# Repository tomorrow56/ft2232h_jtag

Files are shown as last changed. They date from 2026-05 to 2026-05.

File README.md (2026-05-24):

## FT2232HL JTAG Adapter

### Function

Can be used as Xilinx JTAG downloader & USB-to-UART bridge simultaneously following [this](https://gist.github.com/rikka0w0/24b58b54473227502fa0334bbe75c3c1).

Partly pin-to-pin compatible with the CJMCU FT232HL(the purple PCB one) and has a standard 2x7 JTAG connector.

Main chips: FT2232HL(QFP64), ASM1117(3.3V, SOT89), 93LC56(SOP8).

Type-C(tested later so not shown on pic) connection.

Made with Kicad 10.0.

---
以下の手順に従い、EEPROMにデータを書き込むことで、Xilinx JTAG ダウンローダーと USB-UART ブリッジとして同時に使用できます。

```PowerShell
cd <Vivado install dir>\bin\
.\program_ftdi.bat -write -ftdi FT2232H -serial FT000001 -vendor "Your Name" -board "FT2232H-JTAG" -desc "FT2232H JTAG Adapter"
```

* 標準的な2.54mmピッチの 2x7 JTAGコネクタと 1x4 UARTコネクタを搭載しています
* 主要チップ: FT2232HL(QFP64)、ASM1117(3.3V, SOT89)、93LC56(SOP8)
* Type-C コネクタ搭載

#### 設計環境
KiCad 10.0 で設計

#### Gallery

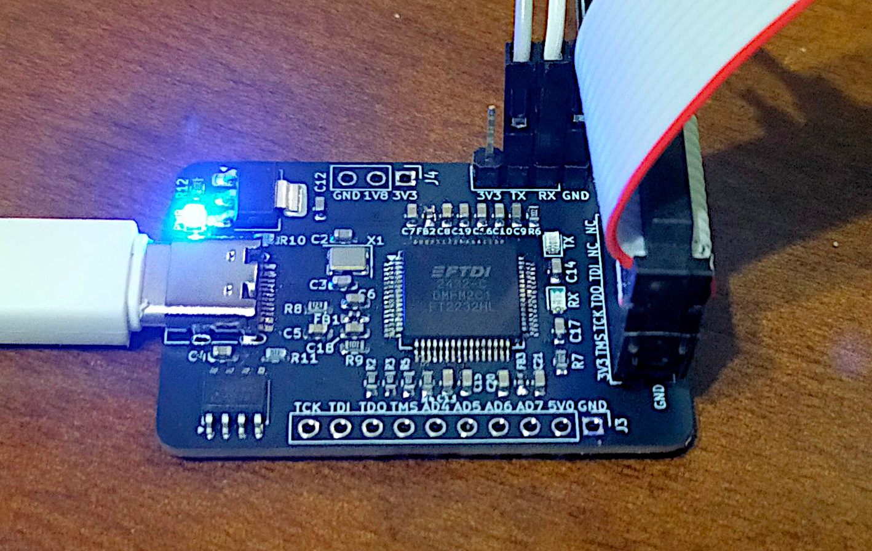
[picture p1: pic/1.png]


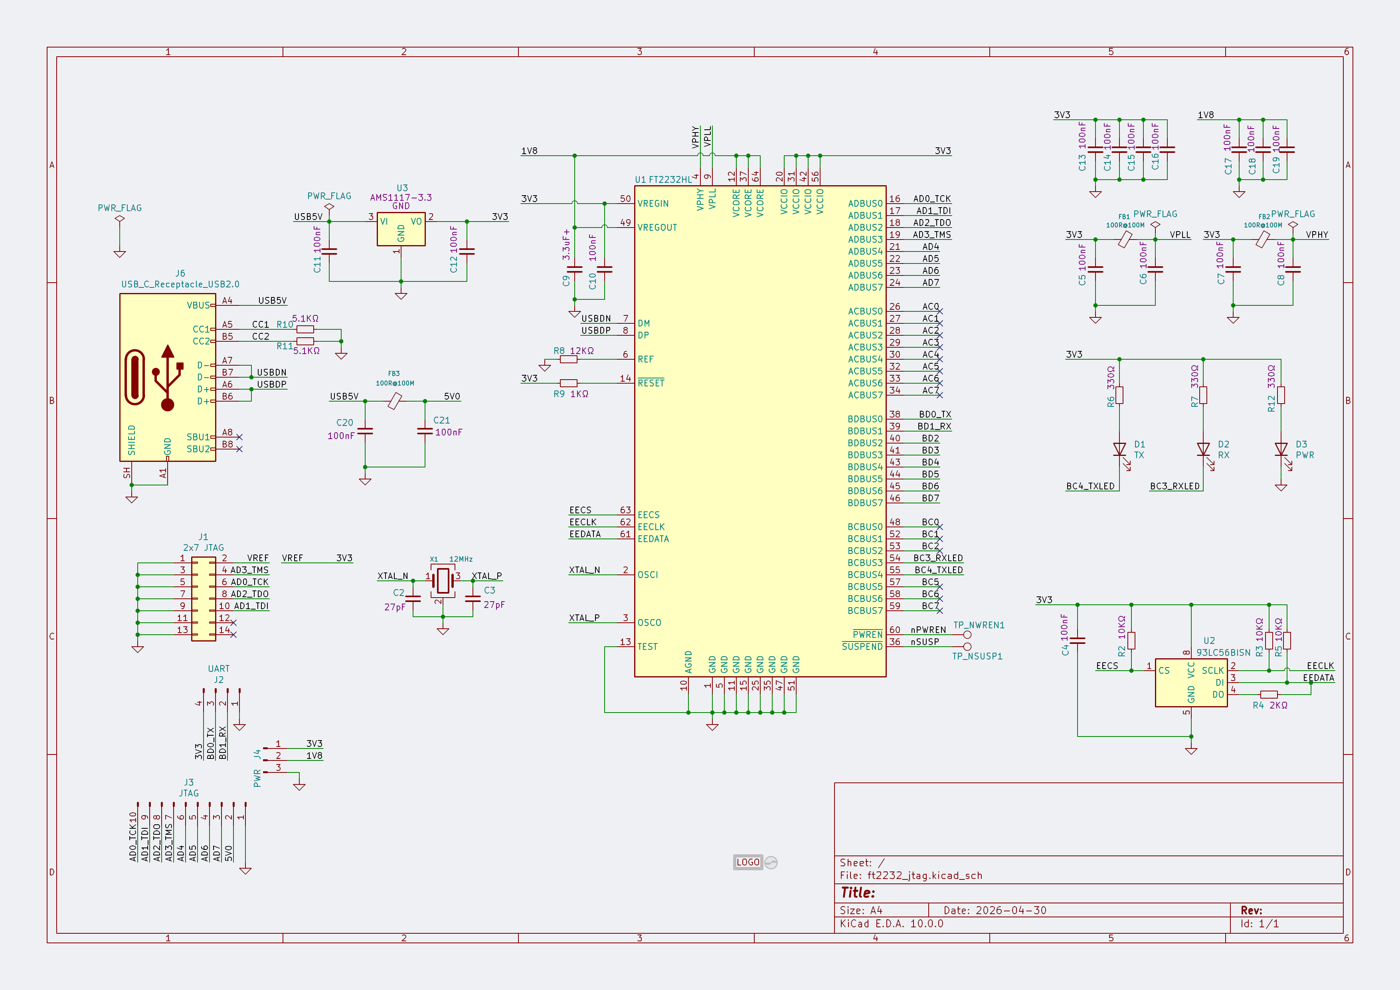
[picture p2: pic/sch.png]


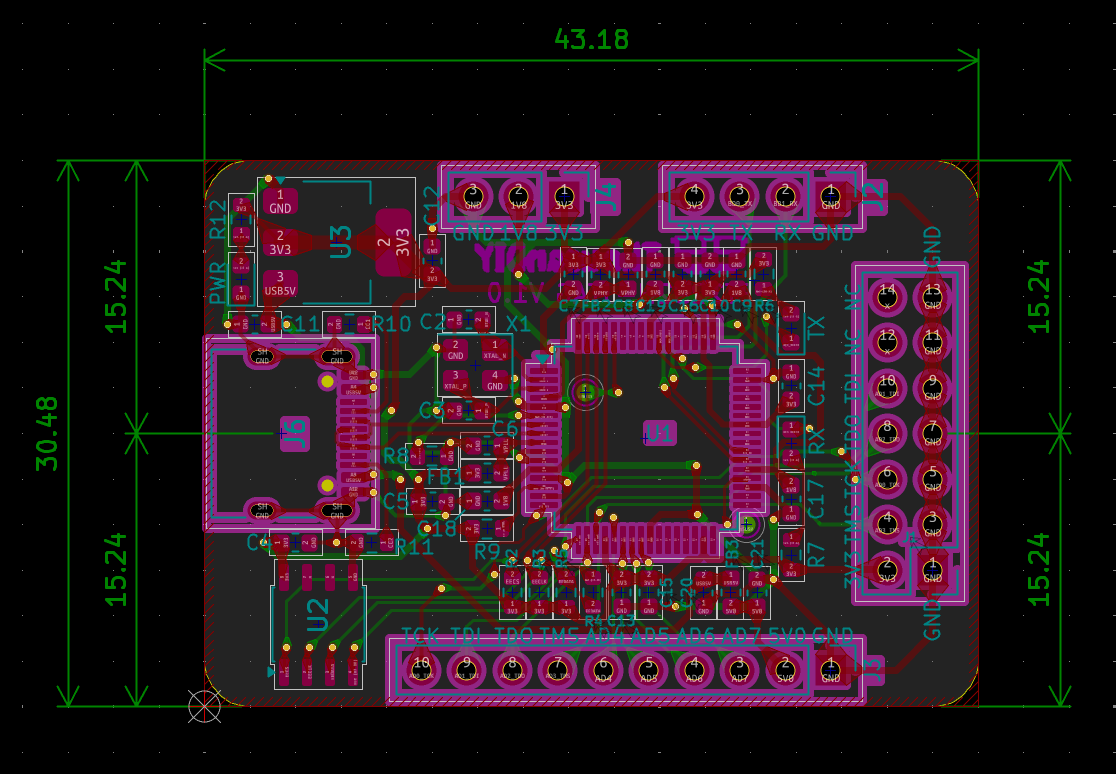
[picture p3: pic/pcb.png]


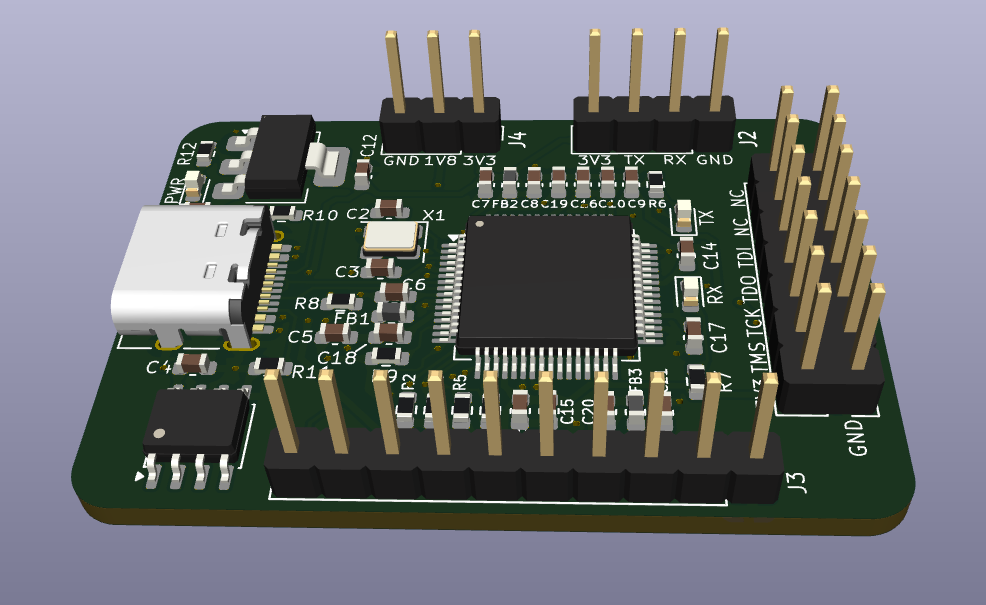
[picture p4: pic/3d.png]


#### License

GPL-v3

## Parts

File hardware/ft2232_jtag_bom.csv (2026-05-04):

ID | 指定子 | フットプリント | 数量 | 名称 | 供給業者、参考資料
1 | C2, C3 | C_0603_1608Metric | 2 | 0805_27pF__270_5%_50V
2 | C4, C5, C6, C7, C8, C10, C11, C12, C13, C14, C15, C16, C17, C18, C19, C20, C21 | C_0603_1608Metric | 17 | 1206_100nF__104_10%_50V
3 | C9 | C_0603_1608Metric | 1 | 0805_3.3nF__332_10%_50V
4 | D1 | LED_0603_1608Metric | 1 | TX
5 | D2 | LED_0603_1608Metric | 1 | RX
6 | D3 | LED_0603_1608Metric | 1 | PWR
7 | FB1, FB2, FB3 | L_0603_1608Metric | 3 | 100R@100M
8 | J1 | PinHeader_2x07_P2.54mm_Vertical | 1 | 2x7 JTAG
9 | J2 | PinHeader_1x04_P2.54mm_Vertical | 1 | UART
10 | J3 | PinHeader_1x10_P2.54mm_Vertical | 1 | JTAG
11 | J4 | PinHeader_1x03_P2.54mm_Vertical | 1 | PWR
12 | J6 | USB_C_Receptacle_HRO_TYPE-C-31-M-12 | 1 | USB_C_Receptacle_USB2.0
13 | logo1 | TDIY-LOGO-S | 1 | Logo_undefined
14 | R2, R3, R5 | R_0603_1608Metric | 3 | 1206_10KΩ__1002_1%
15 | R4 | R_0603_1608Metric | 1 | 1206_2KΩ__2001_1%
16 | R6, R7, R12 | R_0603_1608Metric | 3 | 0805_330Ω__3300_1%
17 | R8 | R_0603_1608Metric | 1 | 0805_12KΩ__1202_1%
18 | R9 | R_0603_1608Metric | 1 | 1206_1KΩ__1001_1%
19 | R10, R11 | R_0603_1608Metric | 2 | 0805_5.1KΩ__5101_1%
20 | TP_NSUSP1, TP_NWREN1 | TestPoint_Pad_D1.0mm | 2 | VALUE
21 | U1 | LQFP-64_10x10mm_P0.5mm | 1 | FT2232HL
22 | U2 | JEITA_SOIC-8_3.9x4.9mm_P1.27mm | 1 | 93LC56BISN
23 | U3 | SOT-223-3_TabPin2 | 1 | SOT-223_AMS1117-3.3
24 | X1 | Crystal_SMD_3225-4Pin_3.2x2.5mm | 1 | 12MHz

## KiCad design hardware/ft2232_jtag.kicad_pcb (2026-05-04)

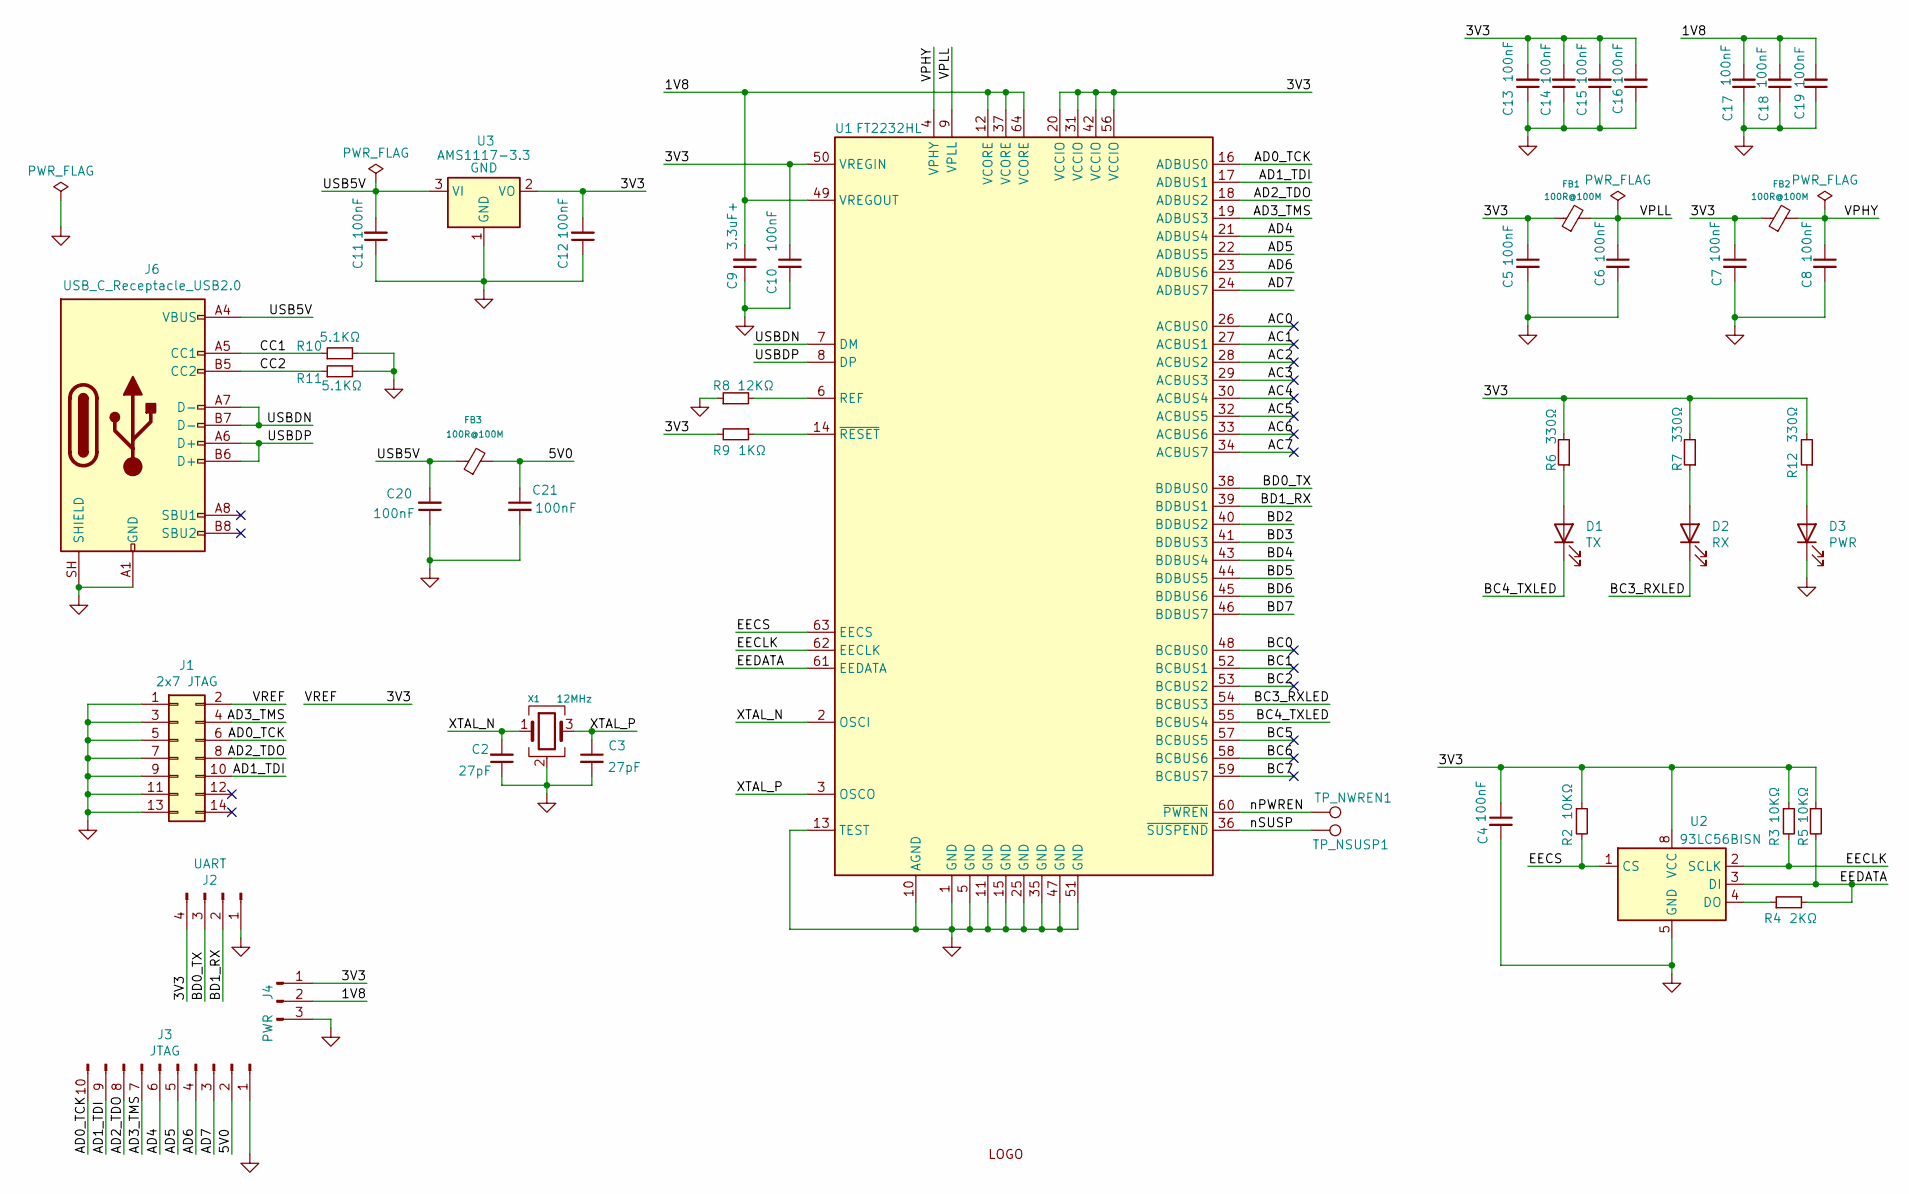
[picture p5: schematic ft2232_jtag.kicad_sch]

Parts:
C2, C3: 0805_27pF__270_5%_50V; C_0603_1608Metric
C4, C5, C6, C7, C8, C10, C11, C12, C13, C14, C15, C16, C17, C18, C19, C20, C21: 1206_100nF__104_10%_50V; C_0603_1608Metric
C9: 0805_3.3nF__332_10%_50V; C_0603_1608Metric
D1: TX; LED_0603_1608Metric
D2: RX; LED_0603_1608Metric
D3: PWR; LED_0603_1608Metric
FB1, FB2, FB3: 100R@100M; L_0603_1608Metric
J1: 2x7 JTAG; PinHeader_2x07_P2.54mm_Vertical
J2: UART; PinHeader_1x04_P2.54mm_Vertical
J3: JTAG; PinHeader_1x10_P2.54mm_Vertical
J4: PWR; PinHeader_1x03_P2.54mm_Vertical
J6: USB_C_Receptacle_USB2.0; USB_C_Receptacle_HRO_TYPE-C-31-M-12
R2, R3, R5: 1206_10KΩ__1002_1%; R_0603_1608Metric
R4: 1206_2KΩ__2001_1%; R_0603_1608Metric
R6, R7, R12: 0805_330Ω__3300_1%; R_0603_1608Metric
R8: 0805_12KΩ__1202_1%; R_0603_1608Metric
R9: 1206_1KΩ__1001_1%; R_0603_1608Metric
R10, R11: 0805_5.1KΩ__5101_1%; R_0603_1608Metric
TP_NSUSP1: VALUE; TestPoint_Pad_D1.0mm
TP_NWREN1: VALUE; TestPoint_Pad_D1.0mm
U1: FT2232HL; LQFP-64_10x10mm_P0.5mm
U2: 93LC56BISN; JEITA_SOIC-8_3.9x4.9mm_P1.27mm
U3: SOT-223_AMS1117-3.3; SOT-223-3_TabPin2
X1: 12MHz; Crystal_SMD_3225-4Pin_3.2x2.5mm
logo1: Logo_undefined; TDIY-LOGO-S

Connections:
/1V8: C9.2, C17.2, C18.2, C19.2, J4.2, U1.12 (VCORE), U1.37 (VCORE), U1.49 (VREGOUT), U1.64 (VCORE)
/3V3: C4.1, C5.1, C7.1, C10.1, C12.2, C13.2, C14.2, C15.2, C16.2, FB1.1, FB2.1, J1.2, J2.4, J4.1, R2.1, R3.1, R5.1, R6.2, R7.2, R9.2, R12.2, U1.20 (VCCIO), U1.31 (VCCIO), U1.42 (VCCIO), U1.50 (VREGIN), U1.56 (VCCIO), U2.8 (VCC), U3.2 (VO)
/5V0: C21.1, FB3.2, J3.2
/AC0: U1.26 (ACBUS0)
/AC1: U1.27 (ACBUS1)
/AC2: U1.28 (ACBUS2)
/AC3: U1.29 (ACBUS3)
/AC4: U1.30 (ACBUS4)
/AC5: U1.32 (ACBUS5)
/AC6: U1.33 (ACBUS6)
/AC7: U1.34 (ACBUS7)
/AD0_TCK: J1.6, J3.10, U1.16 (ADBUS0)
/AD1_TDI: J1.10, J3.9, U1.17 (ADBUS1)
/AD2_TDO: J1.8, J3.8, U1.18 (ADBUS2)
/AD3_TMS: J1.4, J3.7, U1.19 (ADBUS3)
/AD4: J3.6, U1.21 (ADBUS4)
/AD5: J3.5, U1.22 (ADBUS5)
/AD6: J3.4, U1.23 (ADBUS6)
/AD7: J3.3, U1.24 (ADBUS7)
/BC0: U1.48 (BCBUS0)
/BC1: U1.52 (BCBUS1)
/BC2: U1.53 (BCBUS2)
/BC3_RXLED: D2.1 (K), U1.54 (BCBUS3)
/BC4_TXLED: D1.1 (K), U1.55 (BCBUS4)
/BC5: U1.57 (BCBUS5)
/BC6: U1.58 (BCBUS6)
/BC7: U1.59 (BCBUS7)
/BD0_TX: J2.3, U1.38 (BDBUS0)
/BD1_RX: J2.2, U1.39 (BDBUS1)
/BD2: U1.40 (BDBUS2)
/BD3: U1.41 (BDBUS3)
/BD4: U1.43 (BDBUS4)
/BD5: U1.44 (BDBUS5)
/BD6: U1.45 (BDBUS6)
/BD7: U1.46 (BDBUS7)
/CC1: J6.A5 (CC1), R10.1
/CC2: J6.B5 (CC2), R11.1
/EECLK: R3.2, U1.62 (EECLK), U2.2 (SCLK)
/EECS: R2.2, U1.63 (EECS), U2.1 (CS)
/EEDATA: R4.2, R5.2, U1.61 (EEDATA), U2.3 (DI)
/USB5V: C11.2, C20.2, FB3.1, J6.A4 (VBUS), J6.A9 (VBUS), J6.B4 (VBUS), J6.B9 (VBUS), U3.3 (VI)
/USBDN: J6.A7 (D-), J6.B7 (D-), U1.7 (DM)
/USBDP: J6.A6 (D+), J6.B6 (D+), U1.8 (DP)
/VPHY: C8.1, FB2.2, U1.4 (VPHY)
/VPLL: C6.1, FB1.2, U1.9 (VPLL)
/XTAL_N: C2.2, U1.2 (OSCI), X1.1
/XTAL_P: C3.1, U1.3 (OSCO), X1.3
/nPWREN: TP_NWREN1.1 (1_1), U1.60 (~PWREN)
/nSUSP: TP_NSUSP1.1 (1_1), U1.36 (~SUSPEND)
GND: C2.1, C3.2, C4.2, C5.2, C6.2, C7.2, C8.2, C9.1, C10.2, C11.1, C12.1, C13.1, C14.1, C15.1, C16.1, C17.1, C18.1, C19.1, C20.1, C21.2, D3.1 (K), J1.1, J1.3, J1.5, J1.7, J1.9, J1.11, J1.13, J2.1, J3.1, J4.3, J6.A1 (GND), J6.A12 (GND), J6.B1 (GND), J6.B12 (GND), J6.SH (SHIELD), R8.1, R10.2, R11.2, U1.1 (GND), U1.5 (GND), U1.10 (AGND), U1.11 (GND), U1.13 (TEST), U1.15 (GND), U1.25 (GND), U1.35 (GND), U1.47 (GND), U1.51 (GND), U2.5 (GND), U3.1 (GND), X1.2 (G), X1.4 (G)
unnamed: D1.2 (A), R6.1
unnamed: D2.2 (A), R7.1
unnamed: D3.2 (A), R12.1
unnamed: R8.2, U1.6 (REF)
unnamed: R9.1, U1.14 (~RESET)
unnamed: R4.1, U2.4 (DO)

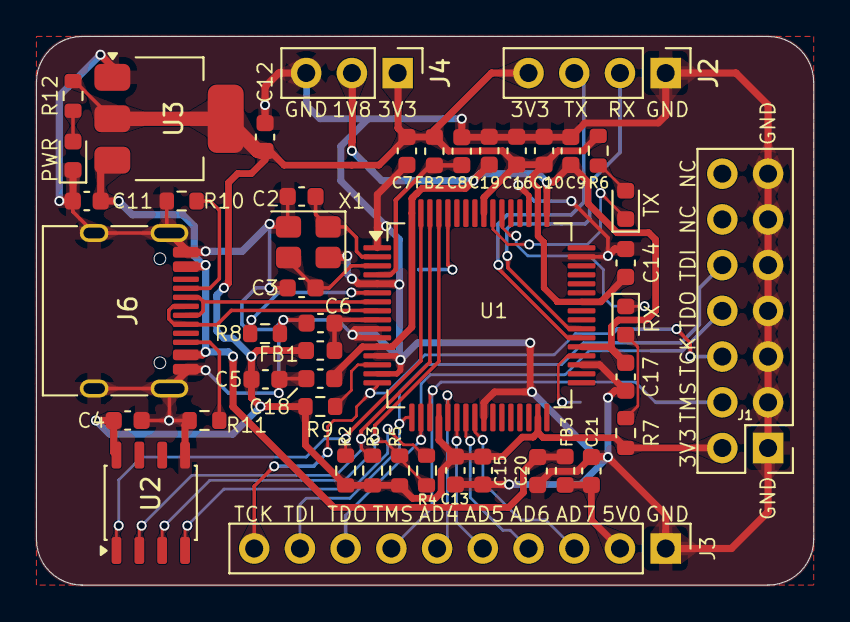
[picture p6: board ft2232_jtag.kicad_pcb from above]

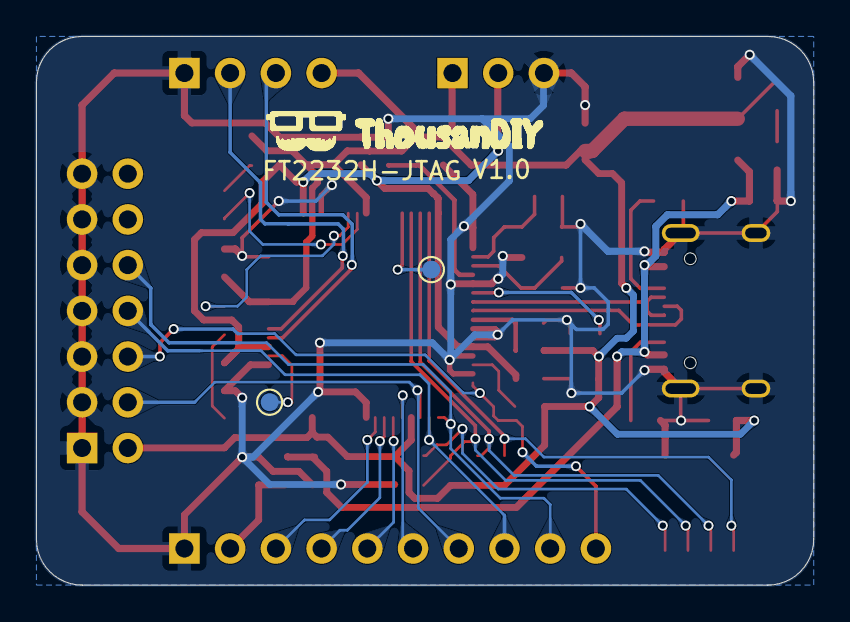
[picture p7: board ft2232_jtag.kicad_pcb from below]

Board: 2 copper layers, 43.2 x 30.5 mm, 49 parts (3 on the bottom side), 36 nets.

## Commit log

2026-05-04 Add .gitignore and remove macOS junk files; update hardware files
    [ft2232_jtag.kicad_pcb, ft2232_jtag.kicad_sch, ft2232_jtag_bom.csv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]
2026-05-04 Remove macOS junk files; add hardware/lib and update files
    [ft2232_jtag.kicad_pcb]
2026-05-24 Update README with EEPROM usage instructions
    Added instructions for using EEPROM with Xilinx JTAG downloader and USB-UART bridge, including a PowerShell command example.
